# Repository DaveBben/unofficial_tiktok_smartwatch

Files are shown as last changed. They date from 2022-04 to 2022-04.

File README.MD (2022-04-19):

# Unofficial TikTok Watch

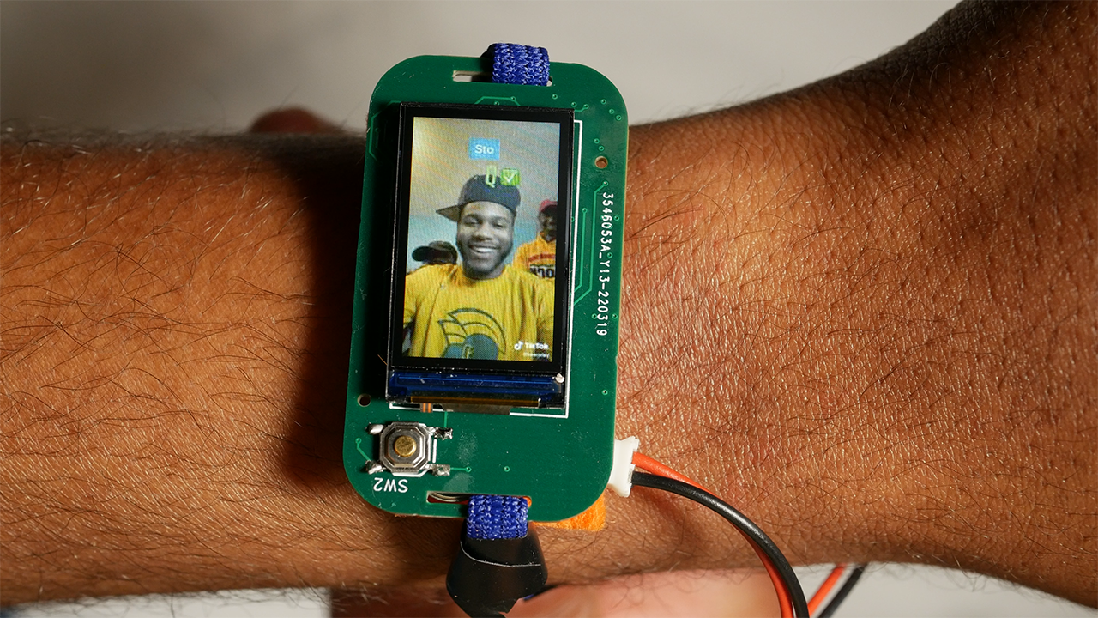
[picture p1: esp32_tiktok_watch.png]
ESP32 TikTok Watch


A  "watch" that plays TikTok videos. Using an unofficial API for Python, we can download TikTok videos then use OpenCV and PyDub to stream the data to the ESP32. On the ESP32 we play that data through an ST7789VW display and max98537a DAC.

You can check out the full youtube video here:
[https://www.youtube.com/watch?v=cla2Bhg6RE0](https://www.youtube.com/watch?v=cla2Bhg6RE0)

## Warning, this is messy 🥲

This is a proof of concept project with a timebox (so I have time to make the YouTube video that accompanies it). Therefore, there's lots of ugly code and scattered ideas throughout. Just a word of caution. 

## Schematics

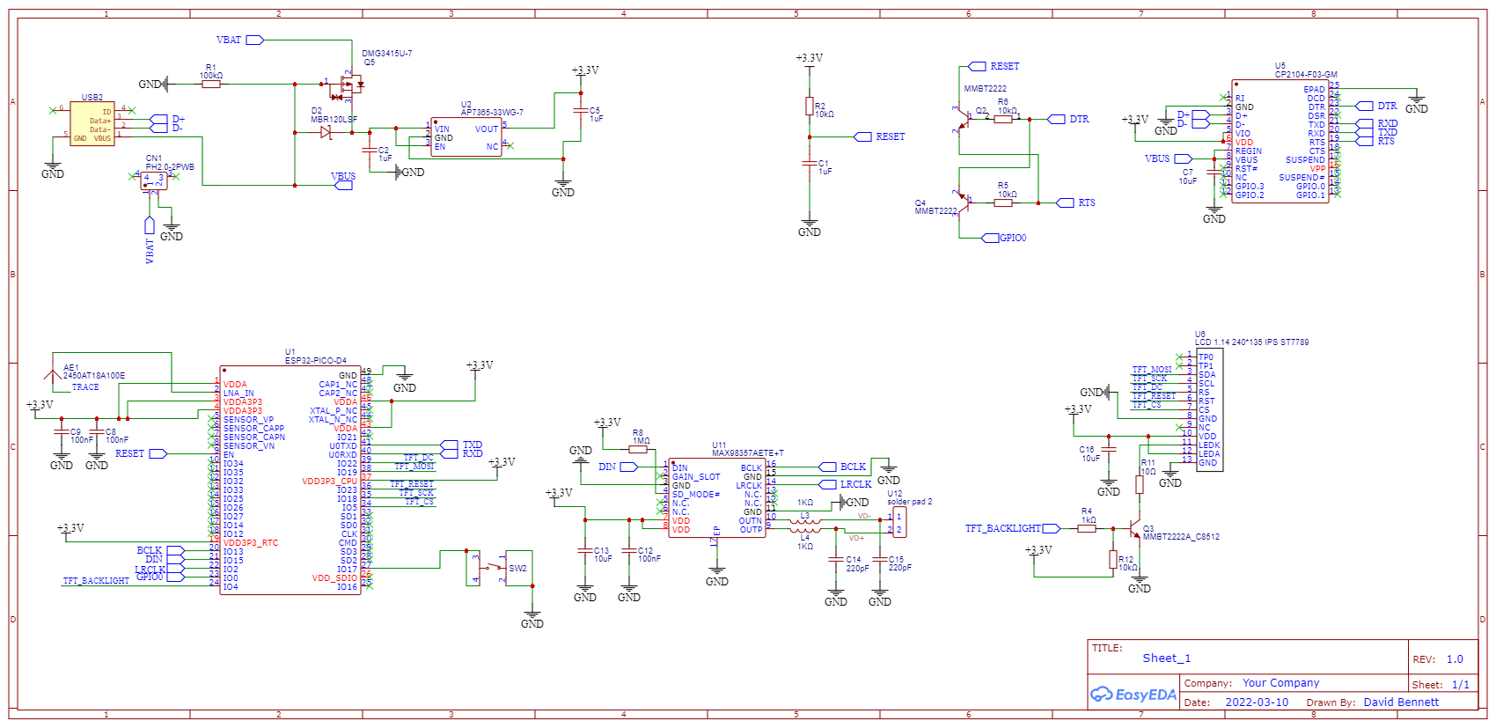
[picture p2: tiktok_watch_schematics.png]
ESP32 TikTok Watch Schematics


## PCB

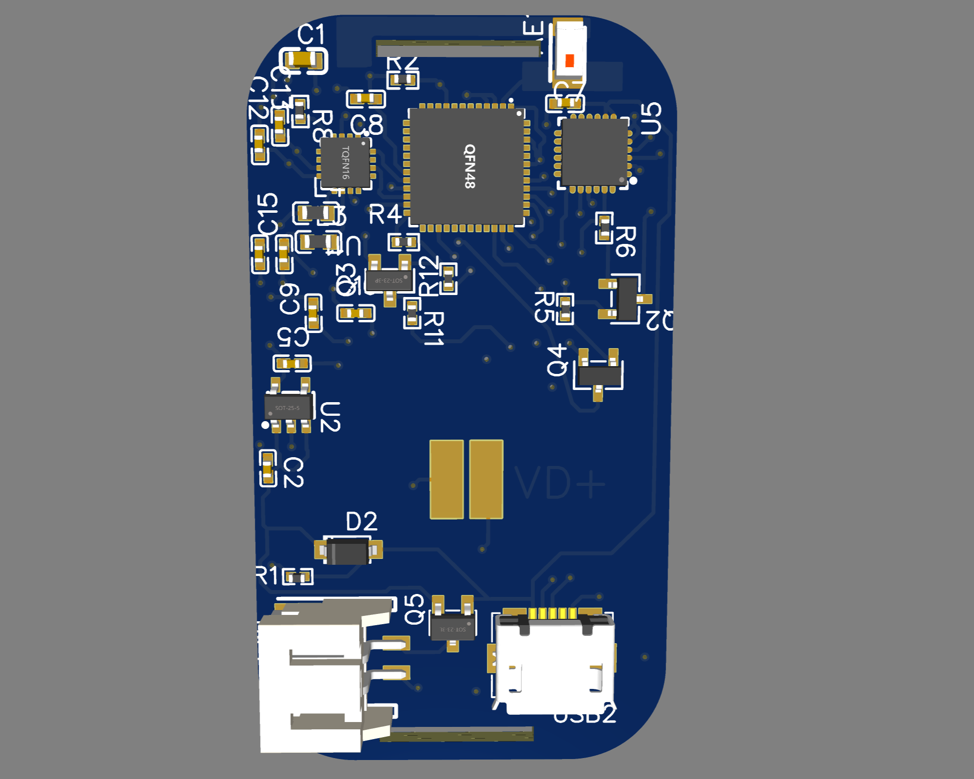
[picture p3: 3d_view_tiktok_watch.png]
ESP32 TikTok Watch PCB


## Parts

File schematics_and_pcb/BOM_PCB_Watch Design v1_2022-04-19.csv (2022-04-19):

ID | Name | Designator | Footprint | Quantity | Manufacturer Part | Manufacturer | Supplier | Supplier Part | Price
1 | 47346-0001 | USB2 | MICRO-USB-SMD_47346-0001 | 1 | 47346-0001 | MOLEX | LCSC | C132560
2 | 2450AT18A100E | AE1 | ANT-SMD_L3.2-W1.6 | 1 | 2450AT18A100E | Johanson Dielectrics | LCSC | C89334
3 | 1uF | C2,C5 | C0402 | 2 | 0402F105M6R3CT | Walsin Tech Corp | LCSC | C408910
4 | 10uF | C7,C13,C16 | C0402 | 3 | CL05A106MQ5NUNC | SAMSUNG | LCSC | C15525
5 | 100nF | C8,C9,C12 | C0402 | 3 | 0402F104M500NT | FH | LCSC | C1581
6 | 220pF | C14,C15 | C0402 | 2 | 0402B221K500NT | FH | LCSC | C1530
7 | PH2.0-2PWB | CN1 | CONN-SMD_2P-P2.00_PH2.0-SPWB | 1 | PH2.0-2PWB Horizontal | BOOMELE | LCSC | C47647
8 | 1KΩ | L3,L4 | L0603 | 2 | BLM18AG102SN1D | MuRata | LCSC | C85824
9 | MMBT2222A_C8512 | Q3 | SOT-23-3_L2.9-W1.3-P1.90-LS2.4-BR | 1 | MMBT2222A | CJ | LCSC | C8512
10 | 100kΩ | R1 | R0402 | 1 | 0402WGF1003TCE | UniOhm | LCSC | C25741
11 | 10kΩ | R2,R12,R5,R6 | R0402 | 4 | 0402WGF1002TCE | UniOhm | LCSC | C25744
12 | 1kΩ | R4 | R0402 | 1 | 0402WGF1001TCE | UniOhm | LCSC | C11702
13 | 1MΩ | R8 | R0402 | 1 | 0402WGF1004TCE | UniOhm | LCSC | C26083
14 | 10Ω | R11 | R0402 | 1 | 0402WGF100JTCE | UniOhm | LCSC | C25077
15 | ESP32-PICO-D4 | U1 | QFN-48_L7.0-W7.0-P0.50-BL-EP5.4 | 1 | ESP32-PICO-D4 | Espressif Systems | LCSC | C193707
16 | CP2104-F03-GM | U5 | QFN-24_L4.0-W4.0-P0.50-BL-EP2.7 | 1 | CP2104-F03-GM | SILICON LABS | LCSC | C47742
17 | MAX98357AETE+T | U11 | TQFN-16_L3.0-W3.0-P0.50-BL-EP1.5 | 1 | MAX98357AETE+T | MAXIM(美信) | LCSC | C910544
18 | MMBT2222 | Q2,Q4 | SOT-23-3_L2.9-W1.4-P1.91-LS2.6-BR | 2 | MMBT2222 | YONGYUTAI(永裕泰) | LCSC | C2891810
19 | 1uF | C1 | C0603 | 1 | CS1608X7R105K250NRB | Samwha Capacitor | LCSC | C513775
20 | MBR120LSF | D2 | SOD-123_L2.8-W1.8-LS3.7-RD | 1 | MBR120LSF | SK | LCSC | C130880
21 | DMG3415U-7 | Q5 | SOT-23-3_L2.9-W1.6-P1.90-LS2.8-BR-CW | 1 | DMG3415U-7 | Diodes Incorporated | LCSC | C96616
22 | LCD 1.14 240*135 IPS ST7789 | U6 | LCD_1.14_240*135_IPS_ST7789 | 1 | IPS 160x80 ST7735 |  | East Rising
23 | TS-1187A-B-A-B | SW2 | SW-SMD_4P-L5.1-W5.1-P3.70-LS6.5-TL-2 | 1 | TS-1187A-B-A-B | XKB Enterprise | LCSC | C318884
24 | AP7365-33WG-7 | U2 | SOT-25_L3.0-W1.6-P0.95-LS2.8-BR | 1 | AP7365-33WG-7 | DIODES | LCSC | C150742

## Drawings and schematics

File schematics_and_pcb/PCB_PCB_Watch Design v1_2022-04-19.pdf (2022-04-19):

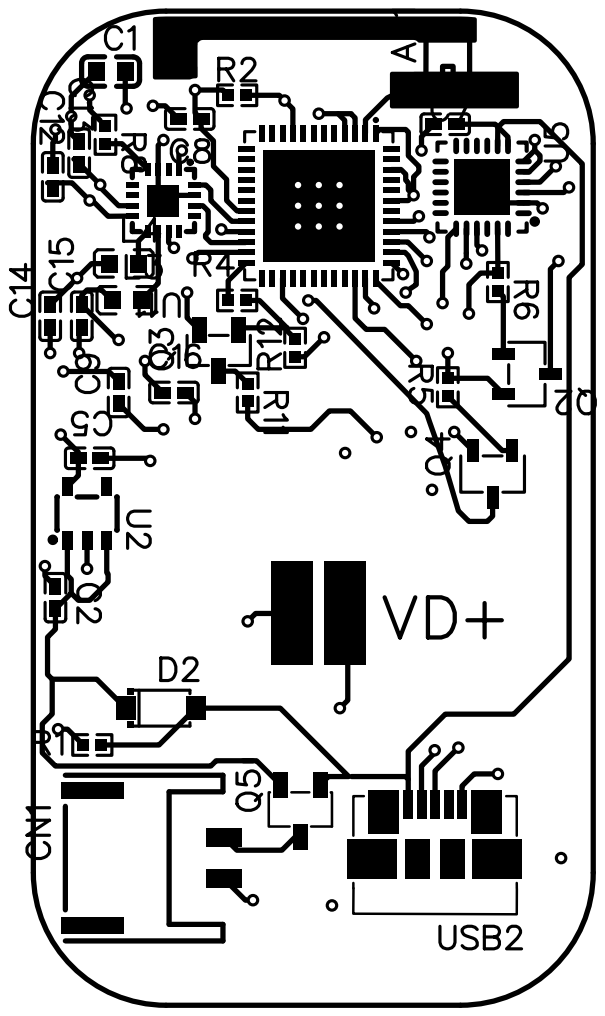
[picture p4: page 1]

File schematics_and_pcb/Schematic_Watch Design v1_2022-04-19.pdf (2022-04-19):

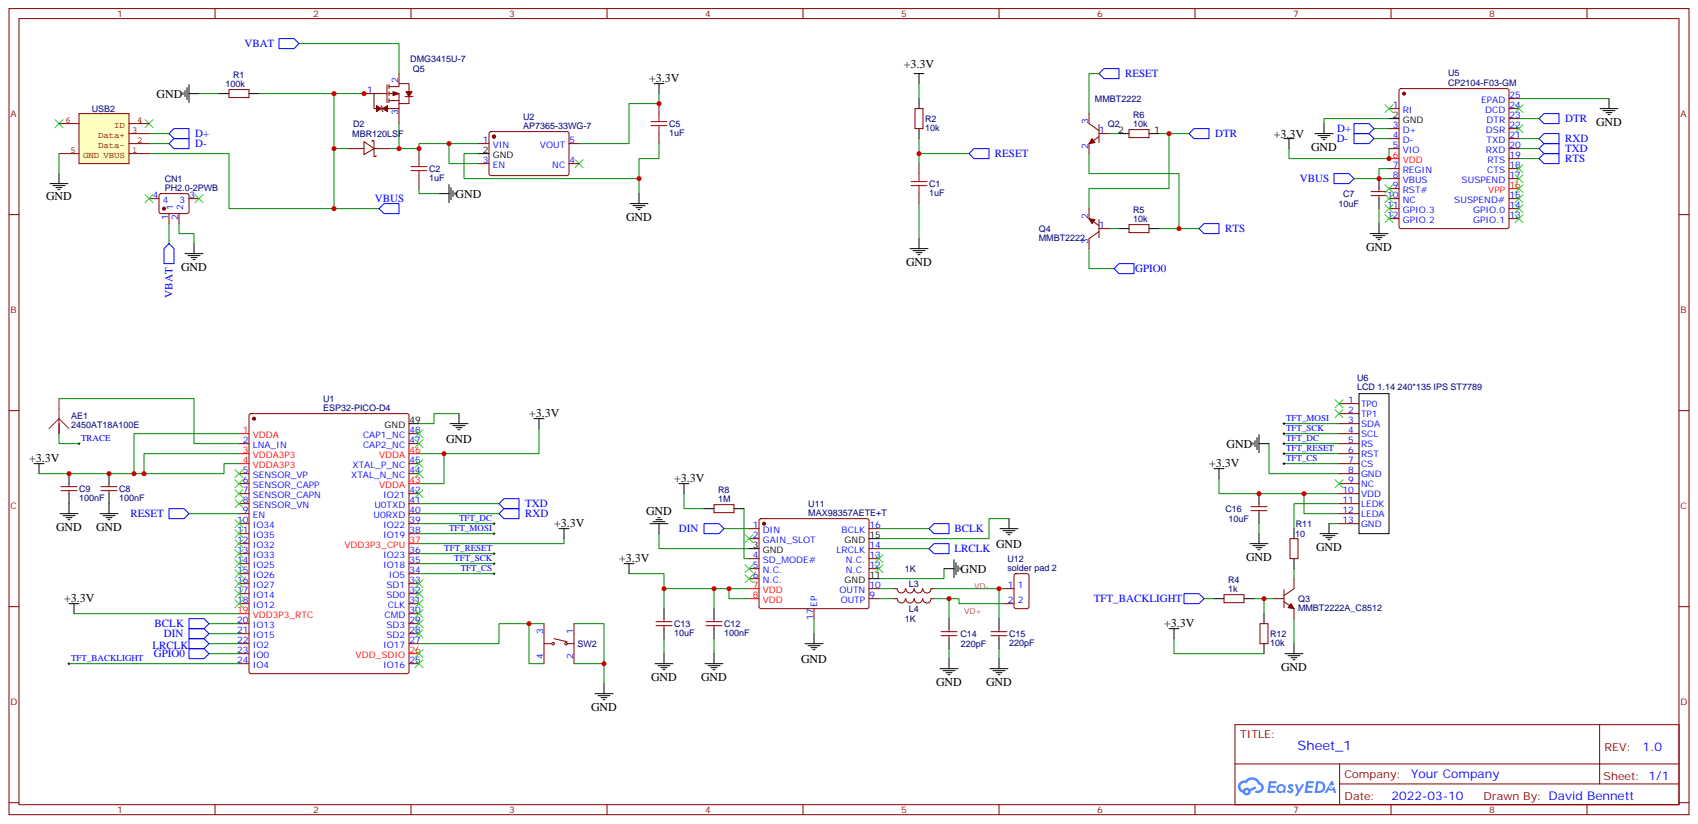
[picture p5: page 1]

Drawn By: David Bennett

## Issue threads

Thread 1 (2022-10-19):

OSError: [Errno 98] error while attempting to bind on address ('0.0.0.0', 8080): address already in use

modi12jin, 2022-10-19:
I am new to this, how can I solve this problem?

```out of range
out of range
out of range
out of range
out of range
Max frame size for video is 4922 with a total a total of 1771 frames
Max frame size for audio is 2940 with a total a total of 1766 frames
Buffers filled
Traceback (most recent call last):
  File "/home/jin/下载/python_server_code/simple_socket.py", line 227, in <module>
    asyncio.run(main())
  File "/home/jin/.local/lib/python3.10/site-packages/nest_asyncio.py", line 35, in run
    return loop.run_until_complete(task)
  File "/home/jin/.local/lib/python3.10/site-packages/nest_asyncio.py", line 90, in run_until_complete
    return f.result()
  File "/usr/lib/python3.10/asyncio/futures.py", line 201, in result
    raise self._exception.with_traceback(self._exception_tb)
  File "/usr/lib/python3.10/asyncio/tasks.py", line 232, in __step
    result = coro.send(None)
  File "/home/jin/下载/python_server_code/simple_socket.py", line 222, in main
    servver = await websockets.serve(data_handler, "0.0.0.0", 8080)
  File "/home/jin/.local/lib/python3.10/site-packages/websockets/legacy/server.py", line 1088, in __await_impl__
    server = await self._create_server()
  File "/usr/lib/python3.10/asyncio/base_events.py", line 1505, in create_server
    raise OSError(err.errno, 'error while attempting '
OSError: [Errno 98] error while attempting to bind on address ('0.0.0.0', 8080): address already in use
```

modi12jin, 2022-10-19:
sorry for the stupid question

```
host_ip = '192.168.0.108'
port = 8000

servver = await websockets.serve(data_handler, host_ip, port)
```

modi12jin, 2022-10-19:
@DaveBben Is this output normal?
```
out of range
out of range
out of range
out of range
out of range
Max frame size for video is 4922 with a total a total of 1771 frames
Max frame size for audio is 2940 with a total a total of 1766 frames
Buffers filled

```

modi12jin, 2022-10-23:
@DaveBben Possibly related to this issue

https://github-com.translate.goog/aaugustin/websockets/issues/1247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

modi12jin, 2022-10-24:
@DaveBben It worked, just very stuck.

> When I built the ESP remote control, I thought about using the web socket to receive images and transmit control commands. But then gave up: [ESP32 Remote Control ESP32-Bilibili] https://b23.tv/bY8JTAM

> As a result, I established two HTTP connections to do two things separately

This may be the direction of follow-up efforts

Closed 2022-10-19.

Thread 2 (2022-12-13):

you-get support

modi12jin, 2022-12-13:
[You-Get](https://you-get.org/) is a tiny command-line utility to download media contents (videos, audios, images) from the Web, in case there is no other handy way to do it.

@DaveBben Hi! Can you support you-get? It supports multiple online video sites to download

> simple_socket.py

```
import os
from you_get import common as you_get

f = open('video_list.text', 'r')

while 1:
	line = f.readline()
	if not line:
		break
	os.system("you-get --no-caption -o ./videos %s" % (line))
	pass

f.close()
```

> video_list.text

```
https://www.bilibili.com/video/BV1ce4y1M7QZ
https://www.bilibili.com/video/BV1MP411T7ri
https://www.bilibili.com/video/BV17e4y1M7Qm
```

modi12jin, 2022-12-15:
```
import flet as ft
import os
import you_get

def main(page: ft.Page):
    def button_clicked(e):
        os.system("you-get --no-caption -o ./videos %s" % (tb1.value))
        t.value = f"完成下载"
        page.update()

    t = ft.Text()
    tb1 = ft.TextField(label="请输入视频链接",hint_text="例如输入bilibili")
    b = ft.ElevatedButton(text="下载", on_click=button_clicked)
    page.add(tb1, b, t)

ft.app(target=main)
```

modi12jin, 2022-12-17:
@DaveBben Looks like it's pretty simple to support, I've succeeded, I'll close this question

```
import you_get

def get_audio_video_info():

    item = random.randint(0, len(videos)-1)
    video_id = videos[item]

    filename = f"{uuid.uuid4()}.mp4"
    path = os.path.join(video_path, filename)
    os.system("you-get --no-caption -O %s -o ./videos %s" % (filename[:-4],video_id))

    # 将视频转换为20FPS。将音频输出到单独的文件
    command = "ffmpeg -y -i {} -filter:v fps=20 {} -filter:a 'volume=0.9' -ac 1 -ar 44100 {}".format(path, os.path.join(video_path, f"converted-{filename}"),'output.wav')
    os.system(command)
    items = [path, 'output.wav']
    return items
```

https://user-images.githubusercontent.com/40233017/208236690-69c64899-8b5c-4a60-bab7-6737ff1241ef.mp4

Closed 2022-12-17.

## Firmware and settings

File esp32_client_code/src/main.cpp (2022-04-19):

#define USE_DMA
#define USE_DMA_TO_TFT

// https://github.com/espressif/esp-idf/issues/3497

#include "JPEGDEC.h"
#include <TFT_eSPI.h>
#include <SPI.h>
#include <WiFi.h>
#include "driver/i2s.h"
#include "driver/gpio.h"
#include <WebSocketsClient.h>
#include <time.h>
#include <sys/time.h>
#include "esp_sntp.h"
#include "driver/gpio.h"

#define SPI_FREQUENCY 80000000
#define SAMPLE_RATE (44100)
#define I2S_NUM (0)
#define I2S_BCK_IO (GPIO_NUM_4)
#define I2S_WS_IO (GPIO_NUM_5)
#define I2S_DO_IO (GPIO_NUM_18)
#define I2S_DI_IO (-1)
#define HEADER_MESSAGE_LENGTH 2

// https://community.platformio.org/t/identifier-is-undefined-setenv-tzset/16162/2
_VOID _EXFUN(tzset, (_VOID));
int _EXFUN(setenv, (const char *__string, const char *__value, int __overwrite));

const uint16_t VIDEO_FRAME_BUFFER_SIZE = 6000;
const uint16_t AUDIO_FRAME_BUFFER_SIZE = 4000;

/**
 * @brief 
 *  Double buffer for DMA
 */
#ifdef USE_DMA
uint16_t dmaBuffer1[2048]; 
uint16_t dmaBuffer2[2048]; 
uint16_t *dmaBufferPtr = dmaBuffer1;
bool dmaBufferSel = 0;
#endif

const char *ssid = "";                       // Enter SSID
const char *password = "";                    // Enter Password
const char *websockets_server_host = "192.168.86.38"; // Enter server adress

WebSocketsClient websocketClient;

JPEGDEC jpeg;

struct Frame
{
    uint8_t video_data[VIDEO_FRAME_BUFFER_SIZE];
    uint8_t audio_data[AUDIO_FRAME_BUFFER_SIZE];
    uint16_t video_data_size;
    uint16_t audio_data_size;
};

/**
 * @brief 
 * Using a circular buffer to store and read frames
 */
struct Circular_Buffer
{
    uint8_t start_pointer;
    uint8_t end_pointer;
    struct Frame *items;
};

#define USE_SERIAL Serial

/*Change to your screen resolution*/
static const uint16_t screenWidth = 135;
static const uint16_t screenHeight = 240;

TFT_eSPI tft = TFT_eSPI(screenWidth, screenHeight); /* TFT instance */

const uint8_t CIRCULAR_BUFFER_SIZE = 4;

int JPEGDraw(JPEGDRAW *pDraw);
void render_image(void *parameter);
void socket_loop(void *parameter);

struct Circular_Buffer *data_buffer;

uint8_t video_frame_buffer[VIDEO_FRAME_BUFFER_SIZE] = {0};
uint8_t audio_frame_buffer[AUDIO_FRAME_BUFFER_SIZE] = {0};

unsigned long lastUpdate = 0;
volatile int fps = 0;
volatile int updates = 0;
volatile uint16_t buttonPressed = 0;
volatile unsigned long lastDebounceTime = 0;

uint8_t isBufferEmpty(struct Circular_Buffer *circular_buff)
{
    if (circular_buff->end_pointer == circular_buff->start_pointer)
    {
        return 1;
    }
    else
    {
        return 0;
    }
}

uint8_t isBufferFull(struct Circular_Buffer *circular_buff)
{
    if (((circular_buff->end_pointer + 1) % CIRCULAR_BUFFER_SIZE) == circular_buff->start_pointer)
    {
        return 1;
    }
    else
    {
        return 0;
    }
}


void read_data_frame(uint8_t *video_buffer, uint16_t *video_size, uint8_t *audio_buffer, uint16_t *audio_size, Circular_Buffer *circular_buffer)
{
    if (!isBufferEmpty(circular_buffer))
    {

        struct Frame *single_frame = &circular_buffer->items[circular_buffer->start_pointer];
        memcpy(video_buffer, single_frame->video_data, single_frame->video_data_size);
        memcpy(audio_buffer, single_frame->audio_data, single_frame->audio_data_size);
        *video_size = single_frame->video_data_size;
        *audio_size = single_frame->audio_data_size;

        circular_buffer->start_pointer = (circular_buffer->start_pointer + 1) % CIRCULAR_BUFFER_SIZE;
    }
}

void reset_buffer(struct Circular_Buffer *circular_buff)
{
    circular_buff->end_pointer = 1;
    circular_buff->start_pointer = 1;
}

/**
 * @brief Since we are not using the button this is not needed
 * 
 * @param arg 
 */
static void IRAM_ATTR gpio_isr(void *arg)
{


    if ((millis() - lastDebounceTime) > 3000)
    {
        lastDebounceTime = millis();
        buttonPressed = 1;
    }
}

void obtain_time()
{
    if (sntp_enabled())
    {
        sntp_stop();
    }

    sntp_setoperatingmode(SNTP_OPMODE_POLL);
    sntp_setservername(0, "pool.ntp.org");
    sntp_init();
}

void init_clock()
{
    struct tm timeinfo;
    time_t now;
    time(&now);
    localtime_r(&now, &timeinfo);
    while (timeinfo.tm_year < (2021 - 1900))
    {
        Serial.println("Time not set, trying...");
        obtain_time();
        time(&now);
        localtime_r(&now, &timeinfo);
        delay(200);
    }

    setenv("TZ", "EST5EDT,M3.2.0/2,M11.1.0", 1); //Eastern Time Zone (NY)
    tzset();
}

void display_clock()
{
    char hour[3];
    char minute[3];
    tft.setTextColor(TFT_WHITE, TFT_BLACK);

    struct tm timeinfo;
    time_t now;

    time(&now);
    localtime_r(&now, &timeinfo);

    strftime(hour, sizeof(hour), "%I", &timeinfo);
    strftime(minute, sizeof(minute), "%M", &timeinfo);
    // tft.fillScreen(TFT_BLACK);
    tft.setTextSize(24);
    tft.setCursor(screenWidth / 2 - 30, 50);
    tft.println(hour);
    tft.setCursor(screenWidth / 2 - 30, 150);
    tft.println(minute);
}

/**
 * @brief No being using because no button
 * 
 */
void request_video()
{
    websocketClient.sendTXT("play");
}

void websocket_event(WStype_t type, uint8_t *payload, size_t length)
{

    switch (type)
    {
    case WStype_DISCONNECTED:
        USE_SERIAL.printf("[WSc] Disconnected!\n");
        reset_buffer(data_buffer);
        vTaskDelay(100 / portTICK_RATE_MS);
        i2s_zero_dma_buffer(I2S_NUM_0);
        break;
    case WStype_CONNECTED:
        USE_SERIAL.printf("[WSc] Connected to url: %s\n", payload);
        websocketClient.sendTXT("play");
        break;
    case WStype_TEXT:
        USE_SERIAL.printf("[WSc] get text: %s\n", payload);
        if (strcmp((char *)payload, "done") == 0)
        {
            // This delay is a lazy hack
            // basically need to wait until
            // all the i2s transfers are actually
            // done
            vTaskDelay(100 / portTICK_RATE_MS);
            i2s_zero_dma_buffer(I2S_NUM_0);

        }
        break;
    case WStype_BIN:
        if (!isBufferFull(data_buffer))
        {
            if (length > 0)
            {
                //The data will come in packaged. We want to deconstruct and put
                // into audio/video frame

                struct Frame *single_frame = &data_buffer->items[data_buffer->end_pointer];

                // // first two bytes represent video length
                uint16_t video_length = ((uint16_t)payload[0] << 8) | payload[1];
                single_frame->video_data_size = video_length;

                // Serial.printf("Video length is %d\n", video_length);
                memcpy(single_frame->video_data, payload + HEADER_MESSAGE_LENGTH, video_length);
                uint16_t audio_length = length - video_length - HEADER_MESSAGE_LENGTH;
                single_frame->audio_data_size = audio_length;

                // Serial.printf("Audio length is %d\n", audio_length);
                memcpy(single_frame->audio_data, payload + HEADER_MESSAGE_LENGTH + video_length, audio_length);
                data_buffer->end_pointer = (data_buffer->end_pointer + 1) % CIRCULAR_BUFFER_SIZE;
            }
        }
        else
        {
            Serial.println("Buffer is full!");
        }
        break;
    }
}

int JPEGDraw(JPEGDRAW *pDraw)
{
    int iCount;
    iCount = pDraw->iWidth * pDraw->iHeight; // number of pixels to draw in this call
    // Serial.printf("Drawing %d pixels\n", iCount);
    // delay(5000);

    if (dmaBufferSel)
        dmaBufferPtr = dmaBuffer2;
    else
        dmaBufferPtr = dmaBuffer1;
    dmaBufferSel = !dmaBufferSel;


    tft.pushImageDMA(pDraw->x, pDraw->y, pDraw->iWidth, pDraw->iHeight, pDraw->pPixels, dmaBufferPtr);

    return 1;
}

void handle_video(void *pvParameter)
{
    for (;;)
    { // infinite loop
        if (!isBufferEmpty(data_buffer))
        {

            uint16_t video_length, audio_length;
            read_data_frame(video_frame_buffer, &video_length, audio_frame_buffer, &audio_length, data_buffer);
            int i;
            tft.startWrite();
            if (jpeg.openRAM(video_frame_buffer, video_length, JPEGDraw))
            {
                jpeg.setPixelType(RGB565_BIG_ENDIAN);
                // lTime = micros();
                if (jpeg.decode(0, 0, 0))
                {
                    tft.endWrite();
                    updates += 1;
                    size_t written = 0;
                    i2s_write(I2S_NUM_0, audio_frame_buffer, audio_length, &written, portMAX_DELAY);
                }
                else
                {
                    Serial.println("Decode error");
                }
                jpeg.close();
            }
        }

        unsigned long time = millis();

        if (time - lastUpdate >= 1000)
        {
            float overtime = float(time - lastUpdate) / 1000.0;
            fps = floor((float)updates / overtime);

            lastUpdate = time;
            updates = 0;

            Serial.print("FPS: ");
            Serial.println(fps);
        }
    }
}

void setup()
{

    data_buffer = (struct Circular_Buffer *)malloc(sizeof(struct Circular_Buffer));
    data_buffer->items = (struct Frame *)malloc(sizeof *data_buffer->items * CIRCULAR_BUFFER_SIZE);
    data_buffer->end_pointer = 1;
    data_buffer->start_pointer = 1;

    Serial.begin(115200);

    if (data_buffer == NULL or data_buffer->items == NULL)
    {
        Serial.println("Failed to allocate memory on heap");
        return;
    }

    if (dmaBuffer1 == NULL or dmaBuffer2 == NULL)
    {
        Serial.println("Failed to allocate DMA Buffer");
        return;
    }

    WiFi.begin(ssid, password);
    // Wait some time to connect to wifi
    for (int i = 0; i < 10 && WiFi.status() != WL_CONNECTED; i++)
    {
        Serial.print(".");
        delay(1000);
    }

    // Check if connected to wifi
    if (WiFi.status() != WL_CONNECTED)
    {
        Serial.println("No Wifi!");
        return;
    }

    tft.begin();
    tft.initDMA();
    init_clock();
    tft.fillScreen(TFT_BLACK);
    display_clock();

    websocketClient.begin(websockets_server_host, 8080, "/");
    websocketClient.onEvent(websocket_event);

    lastUpdate = millis();

    i2s_config_t i2s_config = {
        .mode = i2s_mode_t(I2S_MODE_MASTER | I2S_MODE_TX), // Only TX
        .sample_rate = SAMPLE_RATE,
        .bits_per_sample = I2S_BITS_PER_SAMPLE_16BIT, // 16-bit per channel
        .channel_format = I2S_CHANNEL_FMT_ONLY_LEFT,  // 2-channels
        .communication_format = i2s_comm_format_t(I2S_COMM_FORMAT_I2S_MSB),
        .intr_alloc_flags = ESP_INTR_FLAG_LEVEL1,
        .dma_buf_count = 64,
        .dma_buf_len = 50,
        .use_apll = false,

    };
    i2s_pin_config_t pin_config = {
        .bck_io_num = 13,
        .ws_io_num = 2,
        .data_out_num = 15,
        .data_in_num = -1 // Not used
    };

    i2s_driver_install(I2S_NUM_0, &i2s_config, 0, NULL);
    i2s_set_pin(I2S_NUM_0, &pin_config);

    size_t written = 0;

    i2s_set_clk(I2S_NUM_0, SAMPLE_RATE, I2S_BITS_PER_SAMPLE_16BIT, I2S_CHANNEL_MONO);

    i2s_zero_dma_buffer(I2S_NUM_0);
    i2s_start(I2S_NUM_0);

    

    // No button, so not using the following

    // install gpio isr service
    // gpio_install_isr_service(0);
    // hook isr handler for specific gpio pin

    // gpio_config_t io_conf = {};
    // io_conf.intr_type = GPIO_INTR_POSEDGE;
    // io_conf.mode = GPIO_MODE_INPUT;
    // io_conf.pull_down_en = GPIO_PULLDOWN_DISABLE;
    // io_conf.pull_up_en = GPIO_PULLUP_DISABLE;
    // io_conf.pin_bit_mask = (1ULL << GPIO_NUM_17);
    // gpio_config(&io_conf);

    // gpio_isr_handler_add(GPIO_NUM_17, gpio_isr, (void *)GPIO_NUM_17);




    xTaskCreatePinnedToCore(
        socket_loop,   /* Function to implement the task */
        "handle_loop", /* Name of the task */
        4096,          /* Stack size in words */
        NULL,          /* Task input parameter */
        1,             /* Priority of the task */
        NULL,          /* Task handle. */
        0);            /* Core where the task should run */

    xTaskCreatePinnedToCore(
        handle_video,             /* Function to implement the task */
        "handle_video",           /* Name of the task */
        4096,                     /* Stack size in words */
        NULL,                     /* Task input parameter */
        configMAX_PRIORITIES - 1, /* Priority of the task */
        NULL,                     /* Task handle. */
        1);                       /* Core where the task should run */
}

void loop()
{
}

void socket_loop(void *parameter)
{
    for (;;)
    { // infinite loop
        while (!isBufferFull(data_buffer))
        {
            if (buttonPressed)
            {
                buttonPressed = 0;
                websocketClient.sendTXT("play");
            }
            websocketClient.loop();
            vTaskDelay(5 / portTICK_RATE_MS);
        }

        vTaskDelay(10 / portTICK_RATE_MS);
    }
}
